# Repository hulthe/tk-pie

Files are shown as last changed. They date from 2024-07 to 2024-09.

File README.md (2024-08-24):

# Tk🥧
Alternatively: **tk-pie**, or **Test Keyboard Please IgnorE**.
A split keyboard design and firmware.

## Directory

### `/lib`
A rust library, and the bulk of the keyboard firmware implementation.
Written using the Embassy framework.

### `/left` and `/right`
Rust binaries, one for each half of the split keyboard.
Most of the actual logic is implemented in `/lib`.

### `/schematic`
KiCad schematics of the keyboard PCBs.

### `/case`
3d-printable files of the keyboard case and related plastics.

### `/editor`
A graphical program for configuring the keyboard layout. Work in progress.

## Firmware development

Required tools:
- Rust
- `probe-rs` for flashing the firmware. Follow instructions at https://probe.rs/
- [`flip-link`](https://github.com/knurling-rs/flip-link/)
- A debug probe of some kind, I recommend a [Pitaya-Link](https://github.com/makerdiary/pitaya-link)

To flash:
- plug in the probe,
- `cd` into either `left` or `right`
- `cargo run`

### Running tests
The keyboad library comes with some unit tests:
```
cargo test -p tk-pie --target x86_64-unknown-linux-gnu
```

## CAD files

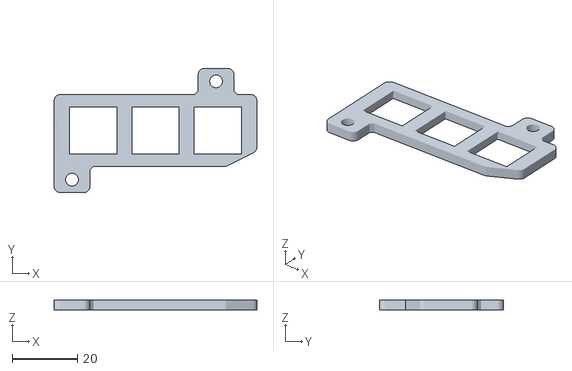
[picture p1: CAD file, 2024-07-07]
case/thumb-frontplate.stl
62.0 x 38.0 x 3.04

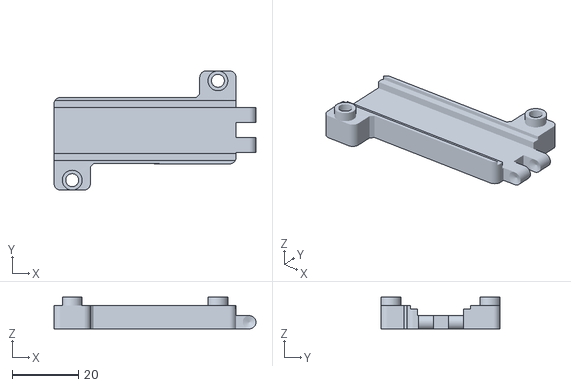
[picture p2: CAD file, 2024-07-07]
case/thumb-backplate.stl
61.0 x 36.0 x 9.63

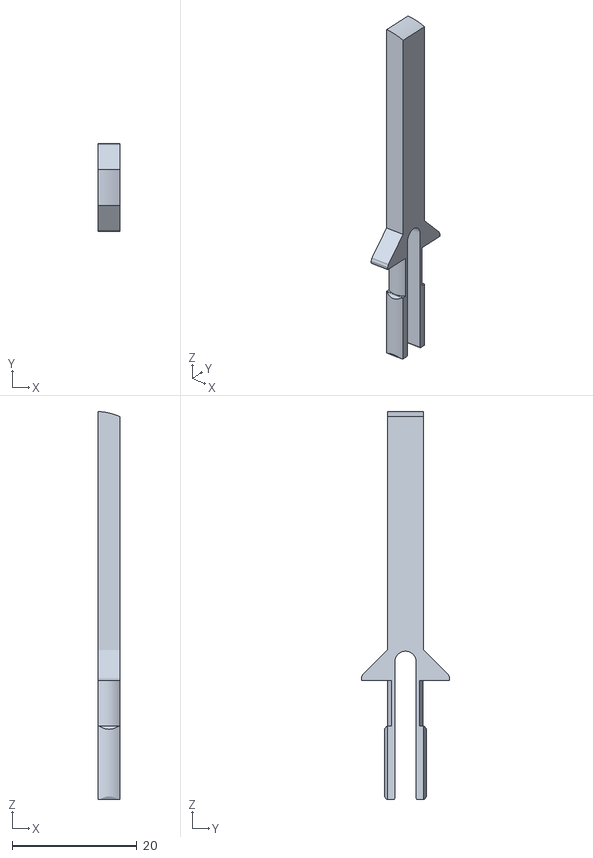
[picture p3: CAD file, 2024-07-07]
case/leg-long.stl
3.50 x 14.2 x 62.3

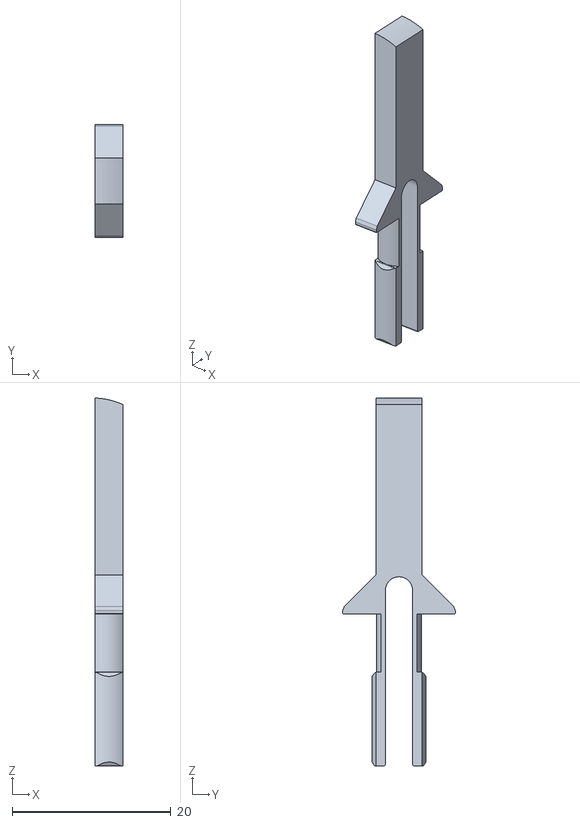
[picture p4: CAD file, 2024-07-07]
case/leg.stl
3.50 x 14.2 x 46.3

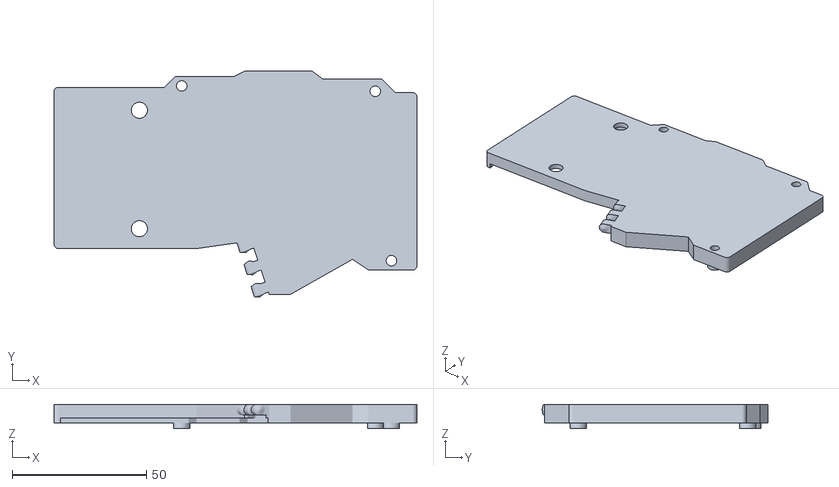
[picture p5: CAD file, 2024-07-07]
case/backplate.stl
135.0 x 84.0 x 9.00

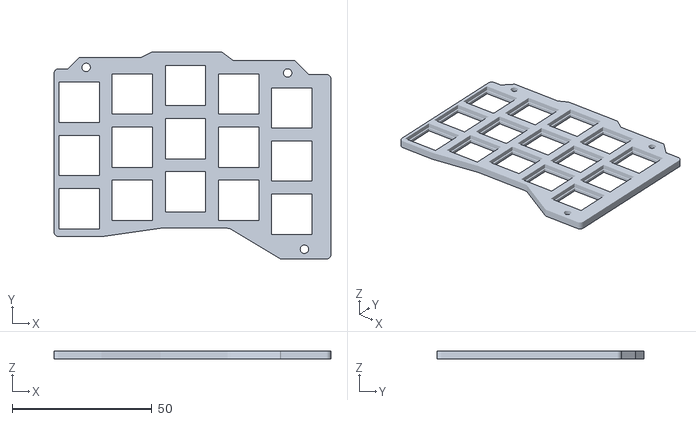
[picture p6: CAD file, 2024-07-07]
case/frontplate.stl
99.0 x 74.0 x 3.00

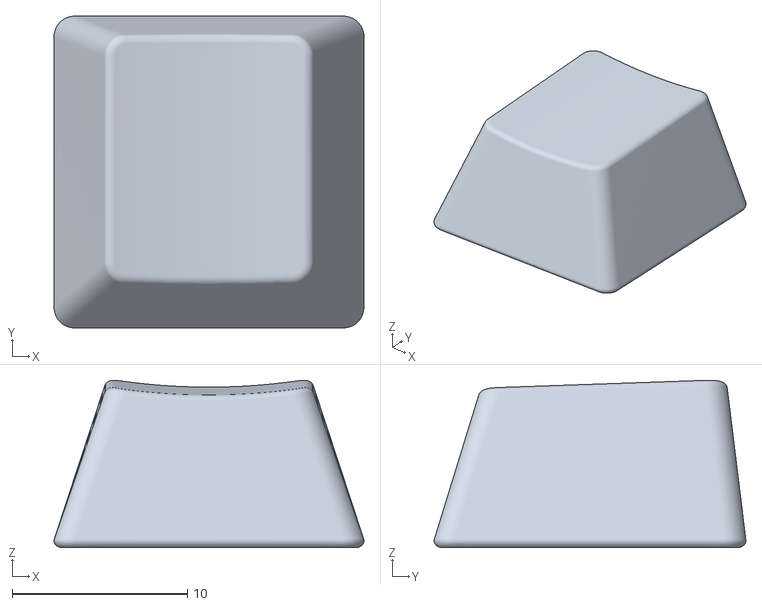
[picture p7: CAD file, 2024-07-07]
case/keycap-filled.stl
17.7 x 17.8 x 9.56

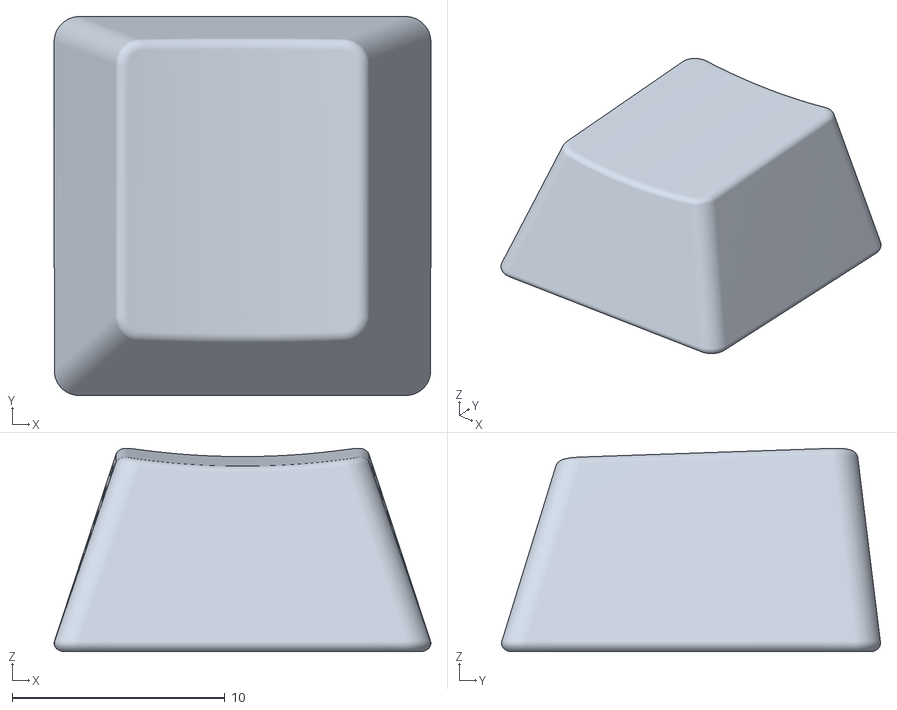
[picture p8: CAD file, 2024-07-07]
case/keycap.stl
17.7 x 17.8 x 9.56

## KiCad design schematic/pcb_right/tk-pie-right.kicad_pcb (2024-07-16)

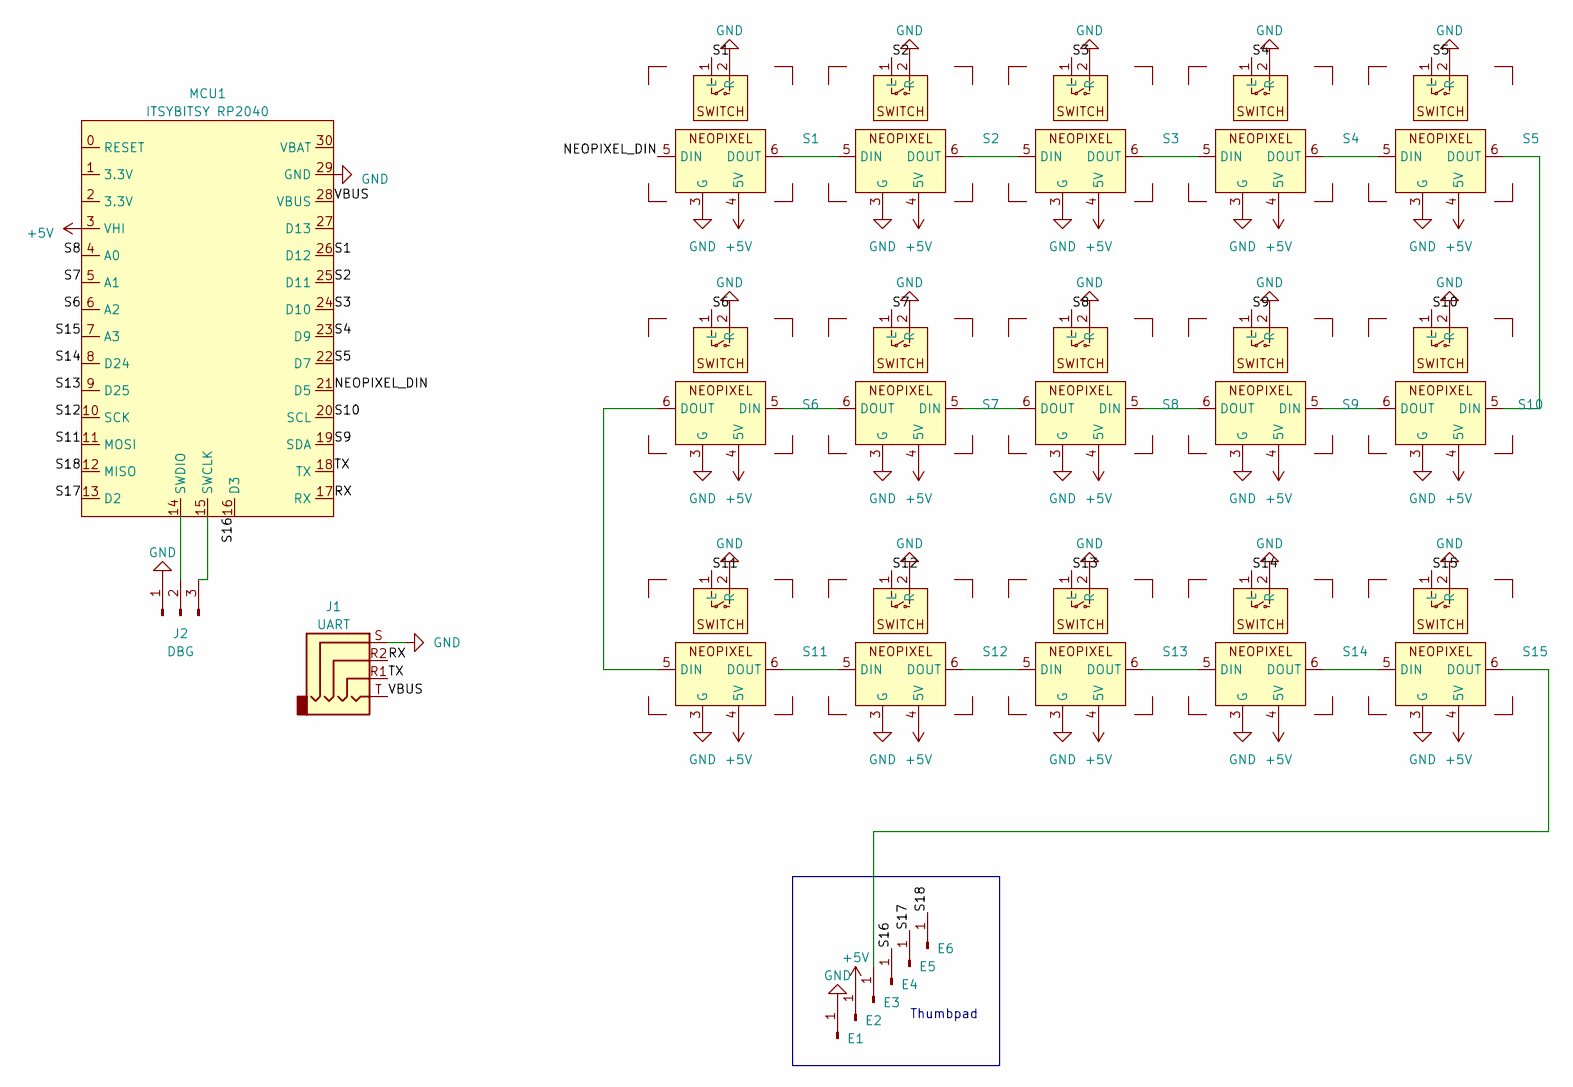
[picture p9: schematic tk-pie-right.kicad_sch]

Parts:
E1, E2, E3, E4, E5, E6: Conn_01x01_Pin; Pin0.9mm
J1: UART; Jack_3.5mm_KoreanHropartsElec_PJ-320D-4A_Horizontal
J2: DBG; PinSocket_1x03_P2.54mm_Vertical
MCU1: ITSYBITSY RP2040; ITSYBITSY BREAKOUT
S1, S2, S11, S12, S13, S14, S15: MX_SW_SOCKET_LED_REV
S3, S4, S5: MX_SW_SOCKET_LED; MX_SW_SOCKET_LED_REV
S6, S7, S8, S9, S10: MX_SW_SOCKET_RGB_REV; MX_SW_SOCKET_LED

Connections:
+5V: E2.1, MCU1.3 (VHI), S1.4 (5V), S2.4 (5V), S3.4 (5V), S4.4 (5V), S5.4 (5V), S6.4 (5V), S7.4 (5V), S8.4 (5V), S9.4 (5V), S10.4 (5V), S11.4 (5V), S12.4 (5V), S13.4 (5V), S14.4 (5V), S15.4 (5V)
/NEOPIXEL_DIN: MCU1.21 (D5), S1.5 (DIN)
/RX: J1.R2, MCU1.17 (RX)
/S1: MCU1.26 (D12), S1.1 (L)
/S2: MCU1.25 (D11), S2.1 (L)
/S3: MCU1.24 (D10), S3.1 (L)
/S4: MCU1.23 (D9), S4.1 (L)
/S5: MCU1.22 (D7), S5.1 (L)
/S6: MCU1.6 (A2), S6.1 (L)
/S7: MCU1.5 (A1), S7.1 (L)
/S8: MCU1.4 (A0), S8.1 (L)
/S9: MCU1.19 (SDA), S9.1 (L)
/S10: MCU1.20 (SCL), S10.1 (L)
/S11: MCU1.11 (MOSI), S11.1 (L)
/S12: MCU1.10 (SCK), S12.1 (L)
/S13: MCU1.9 (D25), S13.1 (L)
/S14: MCU1.8 (D24), S14.1 (L)
/S15: MCU1.7 (A3), S15.1 (L)
/S16: E4.1, MCU1.16 (D3)
/S17: E5.1, MCU1.13 (D2)
/S18: E6.1, MCU1.12 (MISO)
/TX: J1.R1, MCU1.18 (TX)
/VBUS: J1.T, MCU1.28 (VBUS)
GND: E1.1, J1.S, J2.1, MCU1.29 (GND), S1.2 (R), S1.3 (G), S2.2 (R), S2.3 (G), S3.2 (R), S3.3 (G), S4.2 (R), S4.3 (G), S5.2 (R), S5.3 (G), S6.2 (R), S6.3 (G), S7.2 (R), S7.3 (G), S8.2 (R), S8.3 (G), S9.2 (R), S9.3 (G), S10.2 (R), S10.3 (G), S11.2 (R), S11.3 (G), S12.2 (R), S12.3 (G), S13.2 (R), S13.3 (G), S14.2 (R), S14.3 (G), S15.2 (R), S15.3 (G)
unnamed: E3.1, S15.6 (DOUT)
unnamed: J2.2, MCU1.14 (SWDIO)
unnamed: J2.3, MCU1.15 (SWCLK)
unnamed: S1.6 (DOUT), S2.5 (DIN)
unnamed: S2.6 (DOUT), S3.5 (DIN)
unnamed: S3.6 (DOUT), S4.5 (DIN)
unnamed: S4.6 (DOUT), S5.5 (DIN)
unnamed: S6.5 (DIN), S7.6 (DOUT)
unnamed: S7.5 (DIN), S8.6 (DOUT)
unnamed: S8.5 (DIN), S9.6 (DOUT)
unnamed: S5.6 (DOUT), S10.5 (DIN)
unnamed: S9.5 (DIN), S10.6 (DOUT)
unnamed: S6.6 (DOUT), S11.5 (DIN)
unnamed: S11.6 (DOUT), S12.5 (DIN)
unnamed: S12.6 (DOUT), S13.5 (DIN)
unnamed: S13.6 (DOUT), S14.5 (DIN)
unnamed: S14.6 (DOUT), S15.5 (DIN)

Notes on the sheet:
Thumbpad

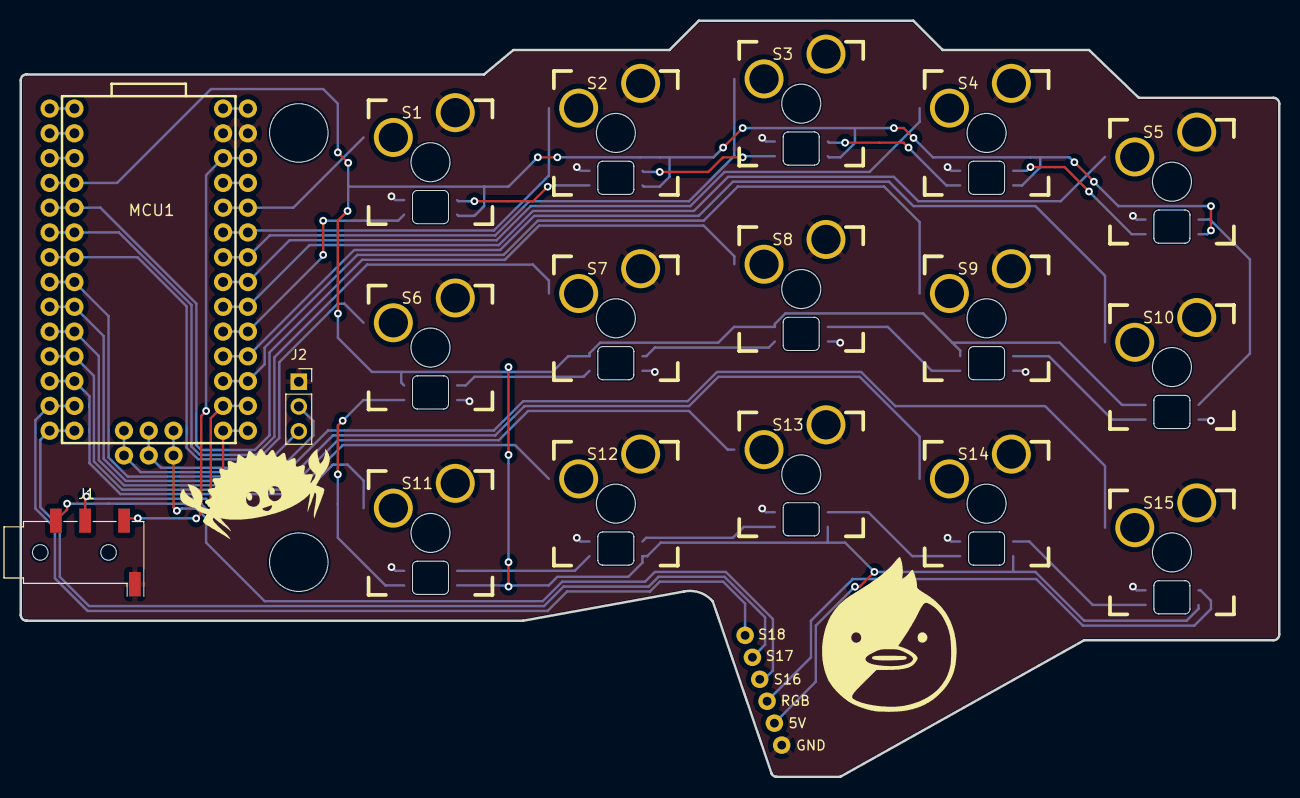
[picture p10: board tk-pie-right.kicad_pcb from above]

Board: 2 copper layers, 129.0 x 77.5 mm, 24 parts (0 on the bottom side), 41 nets.

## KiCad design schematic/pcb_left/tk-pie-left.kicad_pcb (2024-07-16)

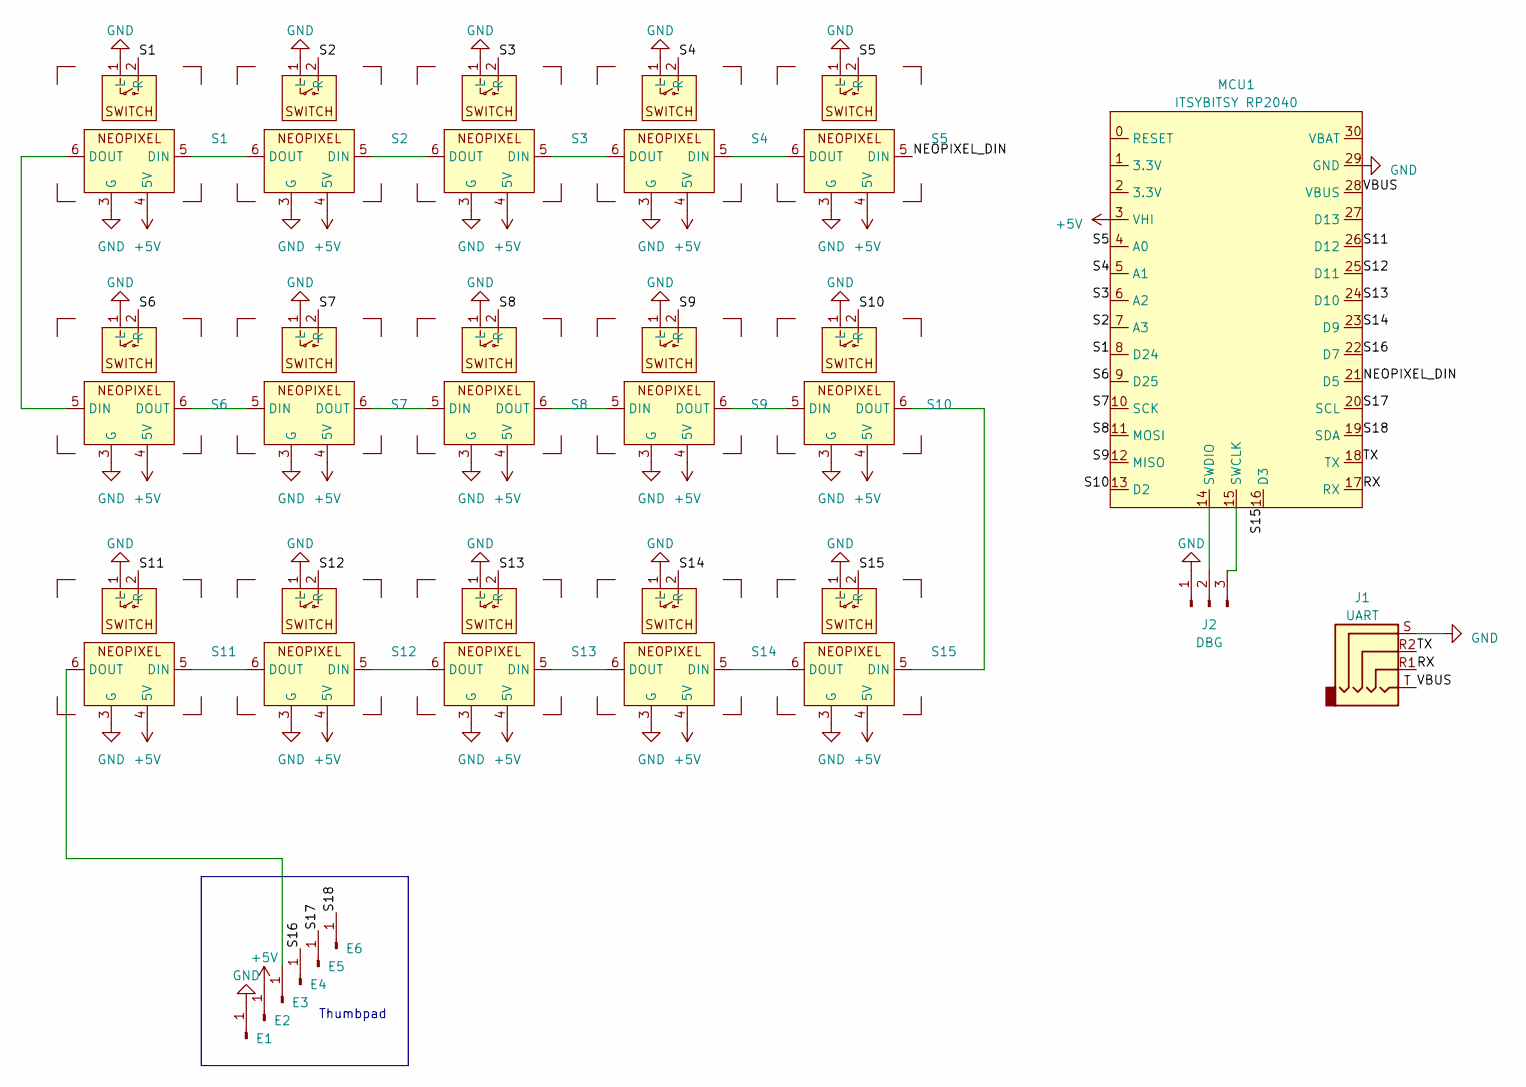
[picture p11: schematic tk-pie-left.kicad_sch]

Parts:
E1, E2, E3, E4, E5, E6: Conn_01x01_Pin; Pin0.9mm
J1: UART; Jack_3.5mm_KoreanHropartsElec_PJ-320D-4A_Horizontal
J2: DBG; PinSocket_1x03_P2.54mm_Vertical
MCU1: ITSYBITSY RP2040; ITSYBITSY BREAKOUT
S1, S2, S11, S12, S13, S14, S15: MX_SW_SOCKET_LED
S3, S4, S5: MX_SW_SOCKET_LED
S6, S7, S8, S9, S10: MX_SW_SOCKET_RGB_REV; MX_SW_SOCKET_LED_REV

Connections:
+5V: E2.1, MCU1.3 (VHI), S1.4 (5V), S2.4 (5V), S3.4 (5V), S4.4 (5V), S5.4 (5V), S6.4 (5V), S7.4 (5V), S8.4 (5V), S9.4 (5V), S10.4 (5V), S11.4 (5V), S12.4 (5V), S13.4 (5V), S14.4 (5V), S15.4 (5V)
/NEOPIXEL_DIN: MCU1.21 (D5), S5.5 (DIN)
/RX: J1.R1, MCU1.17 (RX)
/S1: MCU1.8 (D24), S1.2 (R)
/S2: MCU1.7 (A3), S2.2 (R)
/S3: MCU1.6 (A2), S3.2 (R)
/S4: MCU1.5 (A1), S4.2 (R)
/S5: MCU1.4 (A0), S5.2 (R)
/S6: MCU1.9 (D25), S6.2 (R)
/S7: MCU1.10 (SCK), S7.2 (R)
/S8: MCU1.11 (MOSI), S8.2 (R)
/S9: MCU1.12 (MISO), S9.2 (R)
/S10: MCU1.13 (D2), S10.2 (R)
/S11: MCU1.26 (D12), S11.2 (R)
/S12: MCU1.25 (D11), S12.2 (R)
/S13: MCU1.24 (D10), S13.2 (R)
/S14: MCU1.23 (D9), S14.2 (R)
/S15: MCU1.16 (D3), S15.2 (R)
/S16: E4.1, MCU1.22 (D7)
/S17: E5.1, MCU1.20 (SCL)
/S18: E6.1, MCU1.19 (SDA)
/TX: J1.R2, MCU1.18 (TX)
/VBUS: J1.T, MCU1.28 (VBUS)
GND: E1.1, J1.S, J2.1, MCU1.29 (GND), S1.1 (L), S1.3 (G), S2.1 (L), S2.3 (G), S3.1 (L), S3.3 (G), S4.1 (L), S4.3 (G), S5.1 (L), S5.3 (G), S6.1 (L), S6.3 (G), S7.1 (L), S7.3 (G), S8.1 (L), S8.3 (G), S9.1 (L), S9.3 (G), S10.1 (L), S10.3 (G), S11.1 (L), S11.3 (G), S12.1 (L), S12.3 (G), S13.1 (L), S13.3 (G), S14.1 (L), S14.3 (G), S15.1 (L), S15.3 (G)
unnamed: E3.1, S11.6 (DOUT)
unnamed: J2.2, MCU1.14 (SWDIO)
unnamed: J2.3, MCU1.15 (SWCLK)
unnamed: S1.5 (DIN), S2.6 (DOUT)
unnamed: S1.6 (DOUT), S6.5 (DIN)
unnamed: S2.5 (DIN), S3.6 (DOUT)
unnamed: S3.5 (DIN), S4.6 (DOUT)
unnamed: S4.5 (DIN), S5.6 (DOUT)
unnamed: S6.6 (DOUT), S7.5 (DIN)
unnamed: S7.6 (DOUT), S8.5 (DIN)
unnamed: S8.6 (DOUT), S9.5 (DIN)
unnamed: S9.6 (DOUT), S10.5 (DIN)
unnamed: S10.6 (DOUT), S15.5 (DIN)
unnamed: S11.5 (DIN), S12.6 (DOUT)
unnamed: S12.5 (DIN), S13.6 (DOUT)
unnamed: S13.5 (DIN), S14.6 (DOUT)
unnamed: S14.5 (DIN), S15.6 (DOUT)

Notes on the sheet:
Thumbpad

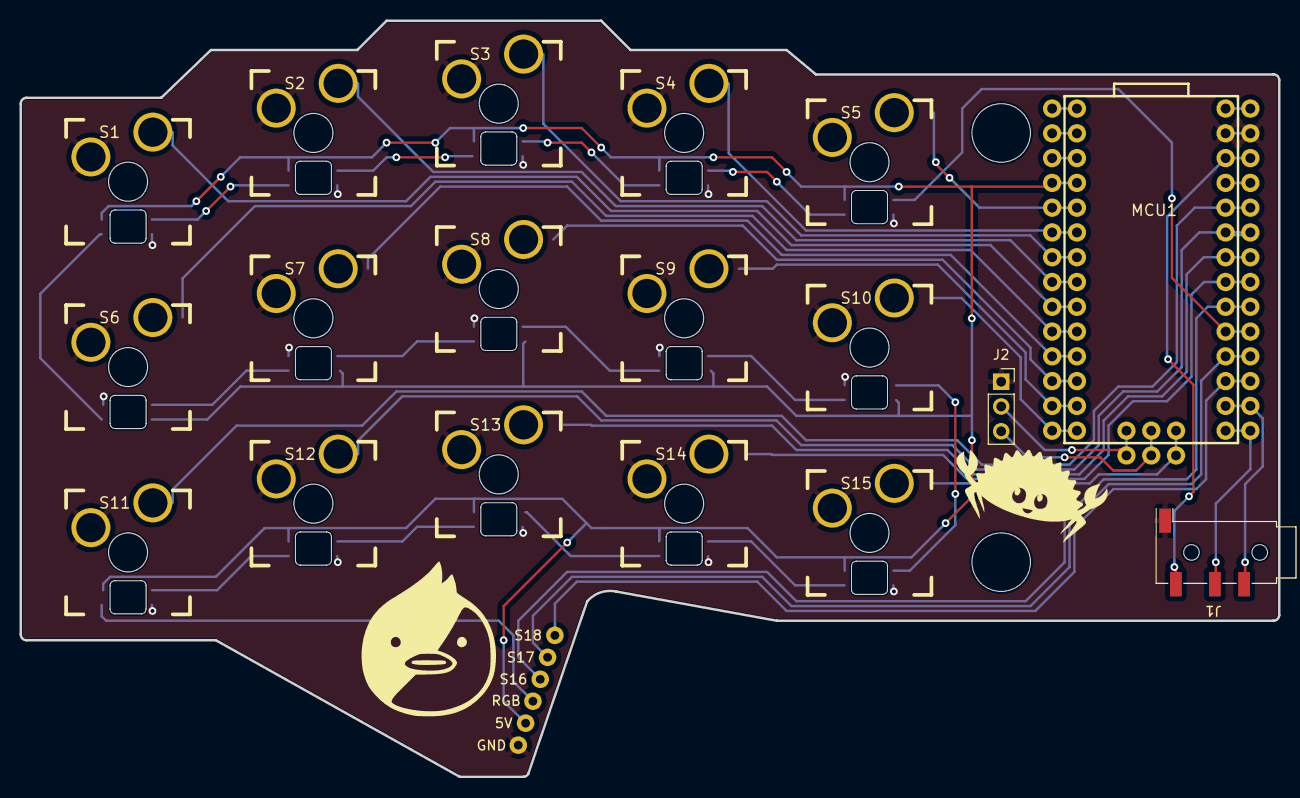
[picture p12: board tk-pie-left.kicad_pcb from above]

Board: 2 copper layers, 129.0 x 77.5 mm, 24 parts (0 on the bottom side), 41 nets.

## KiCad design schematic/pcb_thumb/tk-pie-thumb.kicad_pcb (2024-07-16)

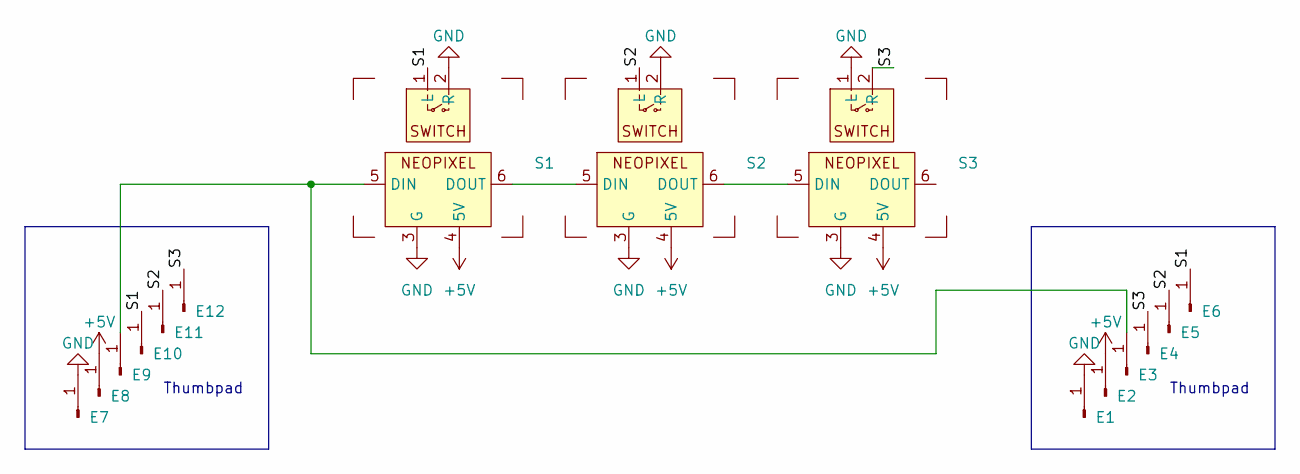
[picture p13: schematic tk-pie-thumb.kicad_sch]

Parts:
E1, E2, E3, E4, E5, E6, E7, E8, E9, E10, E11, E12: Conn_01x01_Pin; Pin0.9mm
S1, S2, S3: MX_SW_SOCKET_LED_REV

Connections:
+5V: E2.1, E8.1, S1.4 (5V), S2.4 (5V), S3.4 (5V)
/S1: E6.1, E10.1, S1.1 (L)
/S2: E5.1, E11.1, S2.1 (L)
/S3: E4.1, E12.1, S3.2 (R)
GND: E1.1, E7.1, S1.2 (R), S1.3 (G), S2.2 (R), S2.3 (G), S3.1 (L), S3.3 (G)
unnamed: E3.1, E9.1, S1.5 (DIN)
unnamed: S1.6 (DOUT), S2.5 (DIN)
unnamed: S2.6 (DOUT), S3.5 (DIN)

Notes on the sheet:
Thumbpad

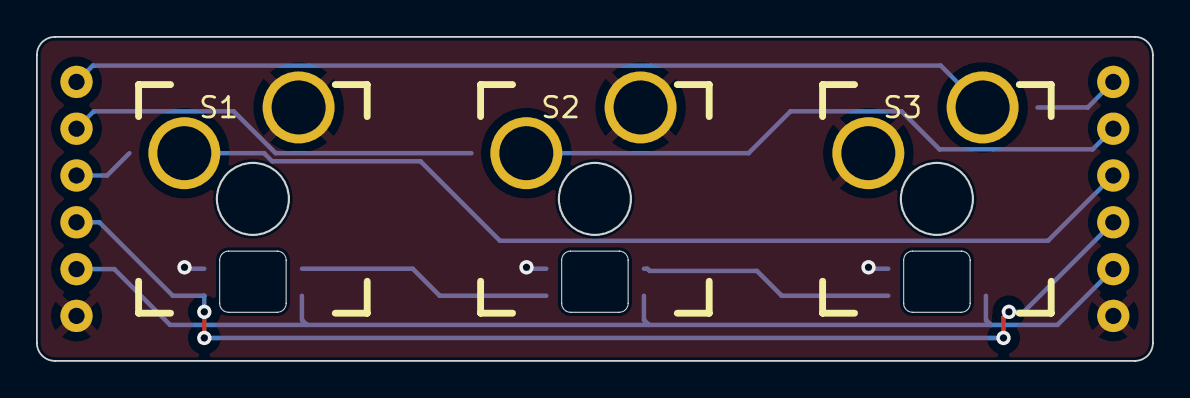
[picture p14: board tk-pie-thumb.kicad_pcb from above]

Board: 2 copper layers, 62.0 x 18.0 mm, 15 parts (0 on the bottom side), 8 nets.

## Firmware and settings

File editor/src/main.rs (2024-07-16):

mod edit_mode;
mod gui;
mod key_mapper;
mod mat;
mod ron_utils;
mod serial;

use clap::Parser;
use edit_mode::EditModeWrapper;
use eyre::eyre;
use gui::GuiSettings;
use mat::Mat;
use ron_utils::RonEdit;
use serde::{Deserialize, Serialize};
use serial::SerialState;
use std::{borrow::BorrowMut, path::PathBuf};
use tk_pie::{layer::Layer, layout::Layout};
use tokio::runtime::Runtime;

#[derive(Parser)]
struct Opt {
    /// Path to device serial port
    device: Option<PathBuf>,
}

fn main() -> eyre::Result<()> {
    let _opt = Opt::parse();

    pretty_env_logger::init();

    let rt = Runtime::new().unwrap();
    let _enter_rt = rt.enter();

    log::info!("starting application");
    let native_options = eframe::NativeOptions::default();
    eframe::run_native(
        "tgnt keyboard editor",
        native_options,
        Box::new(|cc| Ok(Box::new(App::new(cc)))),
    )
    .map_err(|e| eyre!("Failed to run program: {e:?}"))?;

    rt.shutdown_background();

    Ok(())
}

/// We derive Deserialize/Serialize so we can persist app state on shutdown.
#[derive(Deserialize, Serialize, Default)]
#[serde(default)] // if we add new fields, give them default values when deserializing old state
pub struct App {
    layout: RonEdit<Layout>,

    layers: Mat<RonEdit<Layer>>,

    edit_mode: EditModeWrapper,
    gui_settings: GuiSettings,

    #[serde(skip)]
    serial: SerialState,
}

impl App {
    /// Called once before the first frame.
    pub fn new(cc: &eframe::CreationContext<'_>) -> Self {
        // This is also where you can customize the look and feel of egui using
        // `cc.egui_ctx.set_visuals` and `cc.egui_ctx.set_fonts`.

        // Load previous app state (if any).
        // Note that you must enable the `persistence` feature for this to work.
        if let Some(storage) = cc.storage {
            return eframe::get_value(storage, eframe::APP_KEY).unwrap_or_default();
        }

        let layer_str = include_str!("default_layer.ron");
        let layer: Layer = ron::from_str(layer_str).expect("Failed to deserialize default layer");

        let layout_str = include_str!("default_layout.ron");
        let layout: Layout =
            ron::from_str(layout_str).expect("Failed to deserialize default layout");

        let mut layers = Mat::default();
        layers.push_row(RonEdit::new(layer));

        Self {
            layers,
            layout: RonEdit::new(layout),
            ..Self::default()
        }
    }
}

impl eframe::App for App {
    /// Called by the frame work to save state before shutdown.
    fn save(&mut self, storage: &mut dyn eframe::Storage) {
        eframe::set_value(storage, eframe::APP_KEY, self);
    }

    fn raw_input_hook(&mut self, _ctx: &egui::Context, raw_input: &mut egui::RawInput) {
        self.edit_mode
            .handle_input(self.layers.borrow_mut(), raw_input);
    }

    /// Called each time the UI needs repainting, which may be many times per second.
    /// Put your widgets into a `SidePanel`, `TopPanel`, `CentralPanel`, `Window` or `Area`.
    fn update(&mut self, ctx: &egui::Context, _frame: &mut eframe::Frame) {
        let Self {
            layout,
            gui_settings,
            edit_mode,
            layers,
            serial,
        } = self;

        serial.check_serial();

        #[cfg(not(target_arch = "wasm32"))] // no File->Quit on web pages!
        egui::TopBottomPanel::top("top_panel").show(ctx, |ui| {
            // The top panel is often a good place for a menu bar:
            egui::menu::bar(ui, |ui| {
                ui.menu_button("File", |ui| {
                    if ui.button("Quit").clicked() {
                        todo!("implement quit")
                    }
                });
            });
        });

        gui::side_panel::side_panel(ctx, serial, gui_settings, edit_mode, layout, layers);

        gui::central_panel::central_panel(ctx, gui_settings, layout, edit_mode, layers, serial);
    }
}

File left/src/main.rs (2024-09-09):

//! Firmware for Tangentbord1, left half.

// NOTE: the order of attributes matters here..
#![no_main]
#![cfg(target_os = "none")] // only try to compile this for embedded
#![no_std]
#![feature(type_alias_impl_trait)]

extern crate alloc;
extern crate cortex_m_rt;

use alloc::vec::Vec;
use cortex_m_rt::entry;
use embassy_rp::gpio::Pin;
use tk_pie::{
    board::MappedBoard, event::Half, interrupts::Irqs, keyboard::KeyboardConfig, layer::Layer,
    ws2812::Ws2812,
};

#[entry]
fn main() -> ! {
    tk_pie::run(|board| {
        let layers = include_bytes!("layers.pc");
        let Ok(layers): Result<Vec<Vec<Layer>>, _> = postcard::from_bytes(layers) else {
            log::error!("Failed to deserialize layer config");
            loop {}
        };

        let keyboard = KeyboardConfig {
            half: Half::Left,
            pins: [
                // row 1
                board.d24.degrade(),
                board.a3.degrade(),
                board.a2.degrade(),
                board.a1.degrade(),
                board.a0.degrade(),
                // row 2
                board.d25.degrade(),
                board.sck.degrade(),
                board.mosi.degrade(),
                board.miso.degrade(),
                board.d2.degrade(),
                // row 3
                board.d12.degrade(),
                board.d11.degrade(),
                board.d10.degrade(),
                board.d9.degrade(),
                board.d3.degrade(),
                // thumbpad
                board.d7.degrade(),
                board.scl.degrade(),
                board.sda.degrade(),
            ],
            // the index of the LEDs is different than the switch index.
            // each number is the index of the LED for the switch of that index.
            led_map: [4, 3, 2, 1, 0, 5, 6, 7, 8, 9, 14, 13, 12, 11, 10, 15, 16, 17],
            led_driver: Ws2812::new(board.PIO1, Irqs, board.DMA_CH1, board.d5),
            layers,
        };

        let neopixel = Ws2812::new(board.PIO0, Irqs, board.DMA_CH0, board.neopixel);

        MappedBoard {
            USB: board.USB,
            UART0: board.UART0,
            UART1: board.UART1,

            keyboard,

            rx: board.rx,
            tx: board.tx,

            neopixel,
            neopixel_power: board.neopixel_power,
        }
    })
}

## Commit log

2023-04-05 Add PCB schematic
    [tangentbord1-left.kicad_pcb, tangentbord1-left.kicad_sch]
2023-04-05 Add kicad .gitignore
2023-04-16 Tweak left PCB, add right & thumb PCB
    [tangentbord1-left.kicad_pcb, tangentbord1-right.kicad_pcb, tangentbord1-right.kicad_sch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]
2023-04-16 Add export files to kicad gitignore
2023-04-16 Swap RX/TX on pcb_right
    [tangentbord1-right.kicad_pcb, tangentbord1-right.kicad_sch]
2023-05-09 Add light to layer switch key
2023-05-21 Use postcard to serialize uart messages
2023-05-21 Add fado out effect to button presses
2023-05-29 Add uart Header struct
2023-07-21 Switch to layer matrix instead of layer list
2024-02-04 Add naive Compose button impl
2024-02-04 Flash LEDs on USB events
2024-07-07 Add 3d-files for case
    [backplate.stl, frontplate.stl, keycap-filled.stl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]
2024-09-07 Make UART communication more robust
